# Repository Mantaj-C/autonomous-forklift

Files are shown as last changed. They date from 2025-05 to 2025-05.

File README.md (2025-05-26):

## Autonomous Forklift Robot

This project was developed as part of the Electrical Systems Design course at BCIT. It features a fully autonomous forklift robot capable of identifying packages using ArUco markers and transporting them from an unsorted truck to the appropriate sorted location.

### Features:
- **C++ software** running on a **Raspberry Pi 4**
- **OpenCV + ArUco marker detection** for package identification
- **TCP/IP communication** between control modules
- **3D printed chassis and fork**, designed in **SolidWorks**
- **Custom PCB** for motor and sensor interfacing, built with **KiCad**
- **2 stepper motors** for drivetrain movement
- **4 servo motors** for lifting and package handling
- Onboard supervisor: **Tigger** 🐯

All STL files and C++ source code are included in this repository.

---

### 🔗 Project Demo
[Video Link](https://www.linkedin.com/posts/mantaj-chauhan-951b401b5_robotics-opencv-raspberrypi-activity-7332848276444012544-EtOq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)

---

### 📂 Contents
- `/src` – All C++ source code
- `/pcb` – KiCad PCB design files
- `/cad` – STL and SolidWorks files

---

### 🤝 Contributors
- [Mantaj Chauhan](https://www.linkedin.com/in/mantaj-chauhan-951b401b5/)
- [Fuquaan Hussein](https://www.linkedin.com/in/furqaan-hussein-994ba8367/)

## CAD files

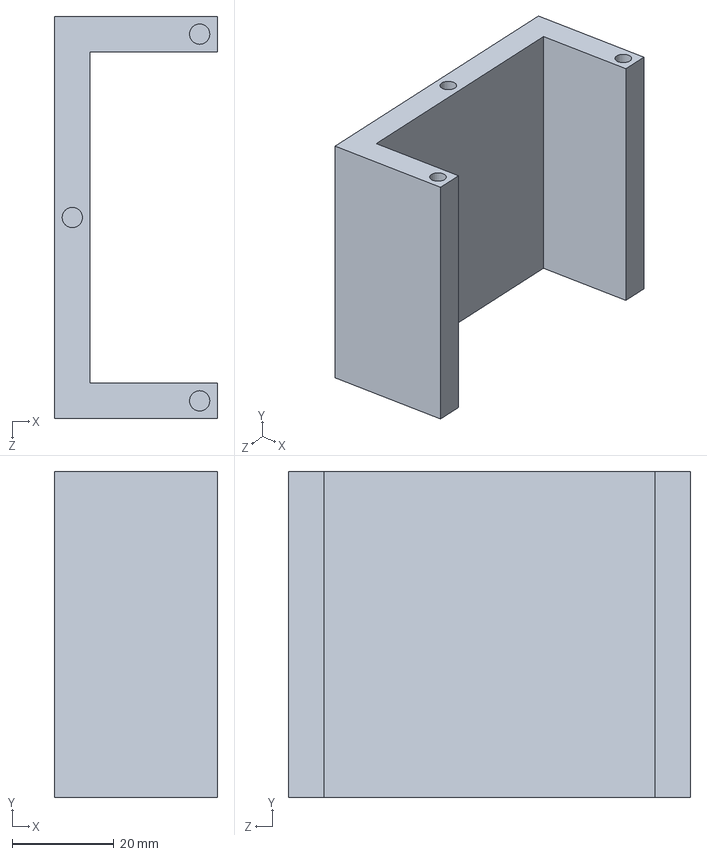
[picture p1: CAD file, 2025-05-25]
cad/sldpart/Power_Bank_Holder.SLDPRT
32.0 x 64.0 x 79.0 mm

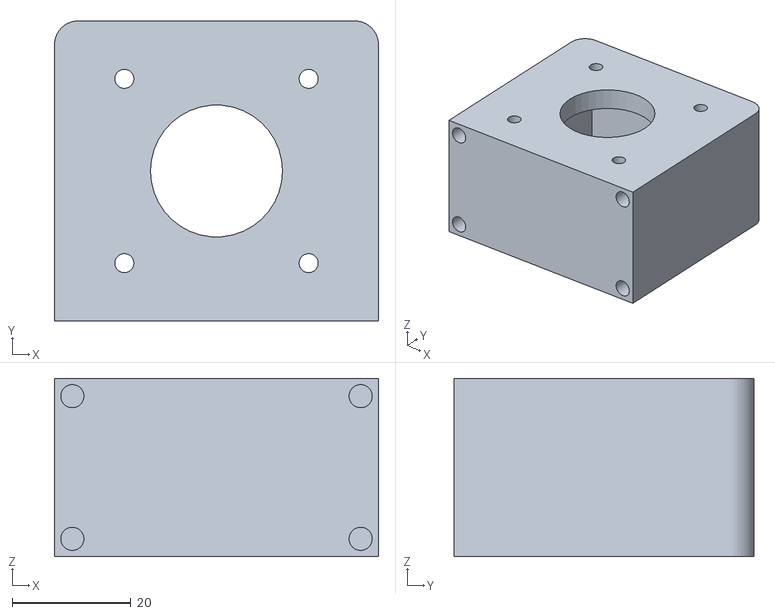
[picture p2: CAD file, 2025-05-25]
cad/stl/Stepper_Motor_Mount.STL
54.5 x 50.5 x 30.0

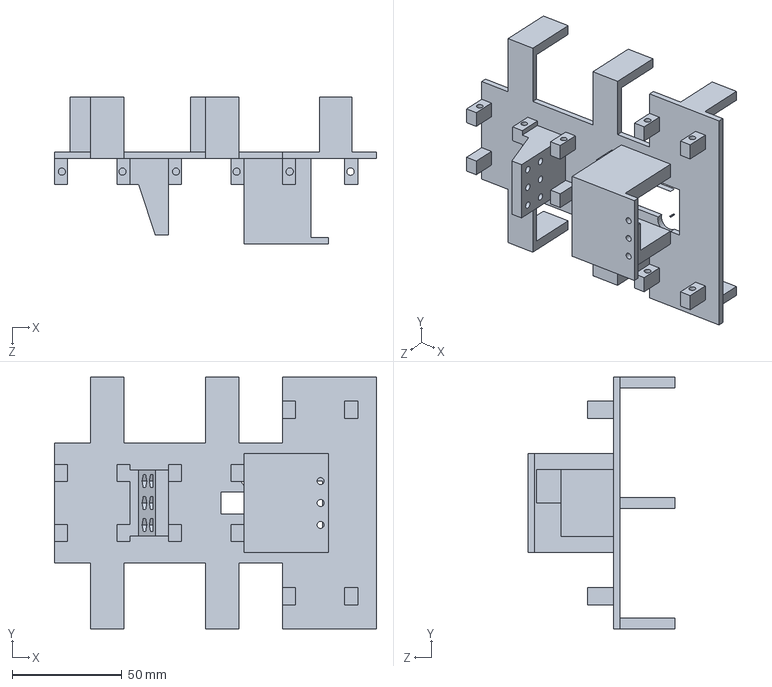
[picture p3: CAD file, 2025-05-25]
cad/sldpart/Fork_Structure.SLDPRT
147.0 x 115.0 x 67.0 mm

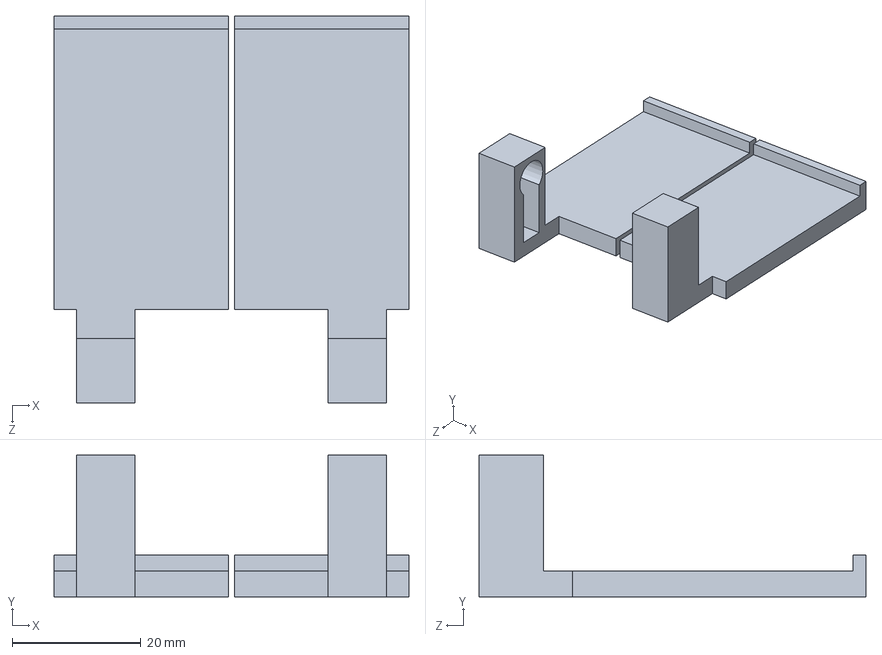
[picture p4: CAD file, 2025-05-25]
cad/sldpart/ServoFork.SLDPRT
55.0 x 22.0 x 60.0 mm

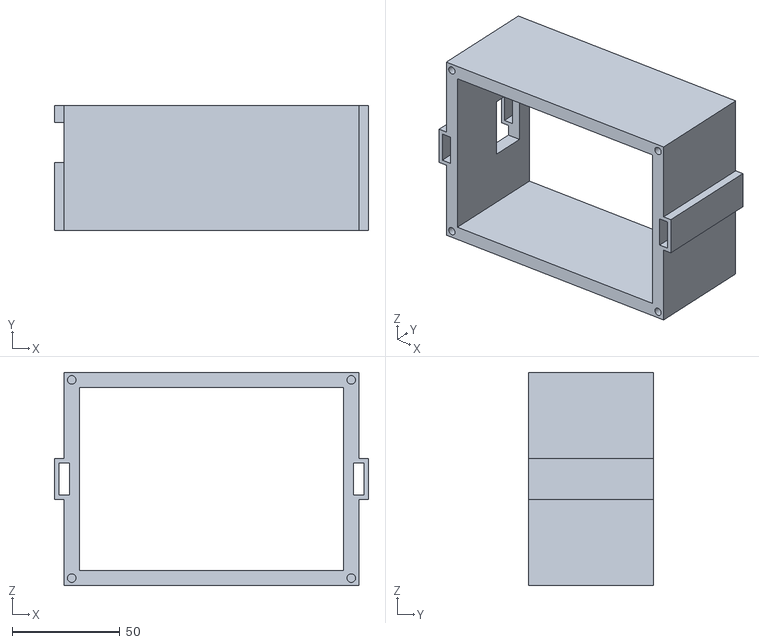
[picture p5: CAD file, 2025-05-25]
cad/stl/Drill_Battery_holder.STL
145.7 x 58.0 x 99.0

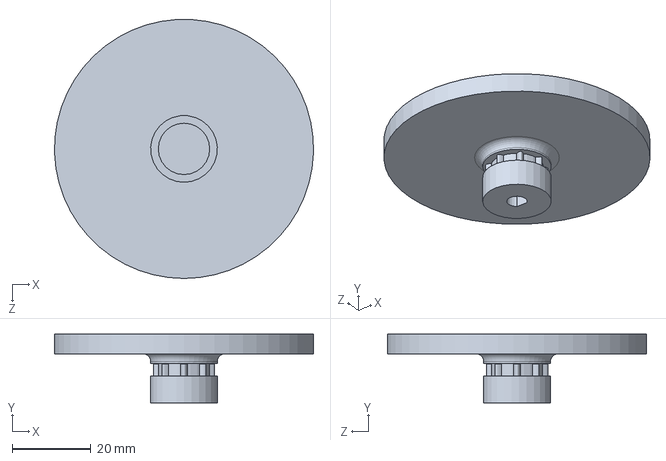
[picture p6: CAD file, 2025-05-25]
cad/sldpart/Stepper_Wheel.SLDPRT
66.0 x 17.5 x 65.9 mm

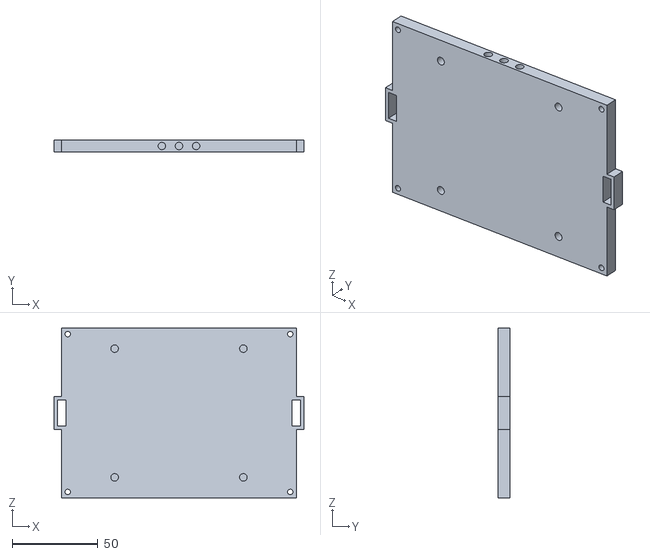
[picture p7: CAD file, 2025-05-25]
cad/stl/Drill_Cover.STL
145.7 x 7.00 x 99.0

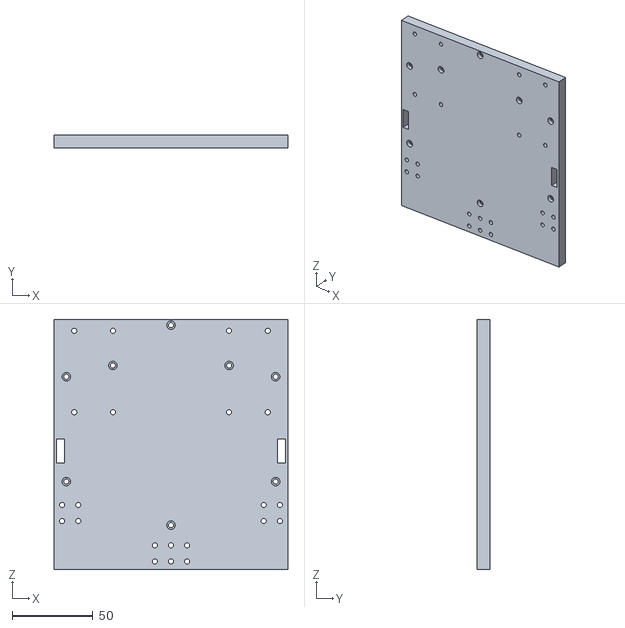
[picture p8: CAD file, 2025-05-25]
cad/stl/Base.STL
145.0 x 8.00 x 155.0

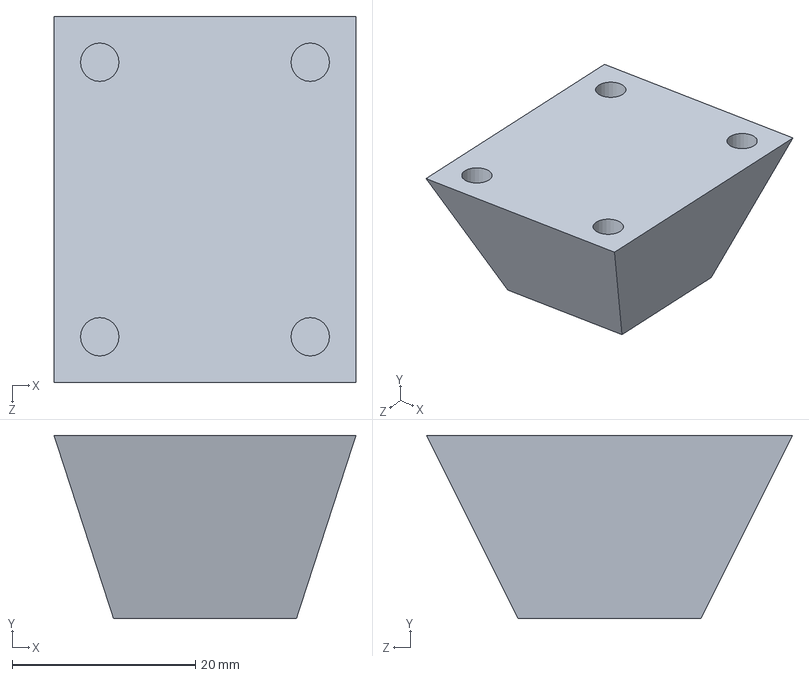
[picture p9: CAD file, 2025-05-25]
cad/sldpart/Roller_Wheel_Attachment.SLDPRT
33.0 x 20.0 x 40.0 mm

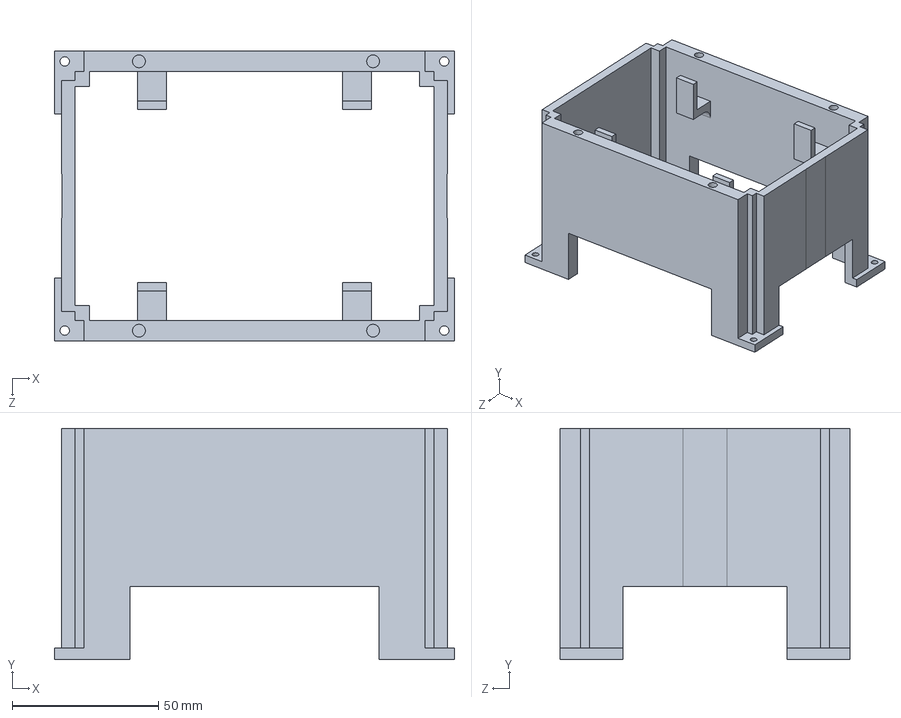
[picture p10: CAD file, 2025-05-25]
cad/sldpart/Pi_Enclosure.SLDPRT
136.7 x 79.0 x 99.0 mm

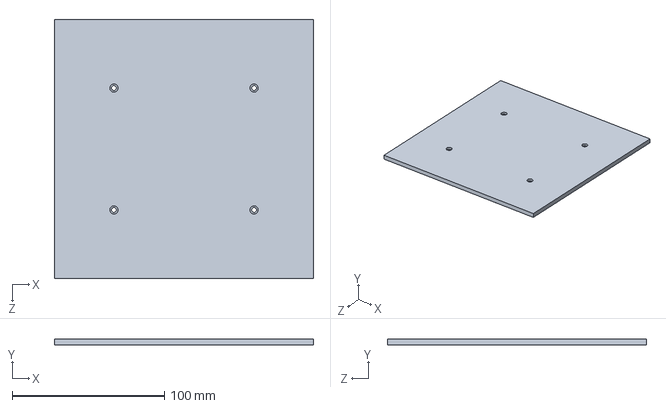
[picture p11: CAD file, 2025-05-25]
cad/sldpart/Aruco_Plate.SLDPRT
170.0 x 4.00 x 170.0 mm

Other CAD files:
cad/stl/Power_Bank_Holder.STL
cad/sldpart/Drill_Cover.SLDPRT
cad/stl/Stepper_Wheel.STL
cad/stl/Roller_Wheel_Attachment.STL
cad/stl/Pi_Enclosure.STL
cad/sldpart/Base.SLDPRT
cad/stl/Fork_Structure.STL
cad/sldpart/Drill_Battery_holder.SLDPRT
cad/sldpart/Stepper_Motor_Mount.SLDPRT
cad/stl/Aruco_Plate.STL
cad/stl/ServoFork.STL

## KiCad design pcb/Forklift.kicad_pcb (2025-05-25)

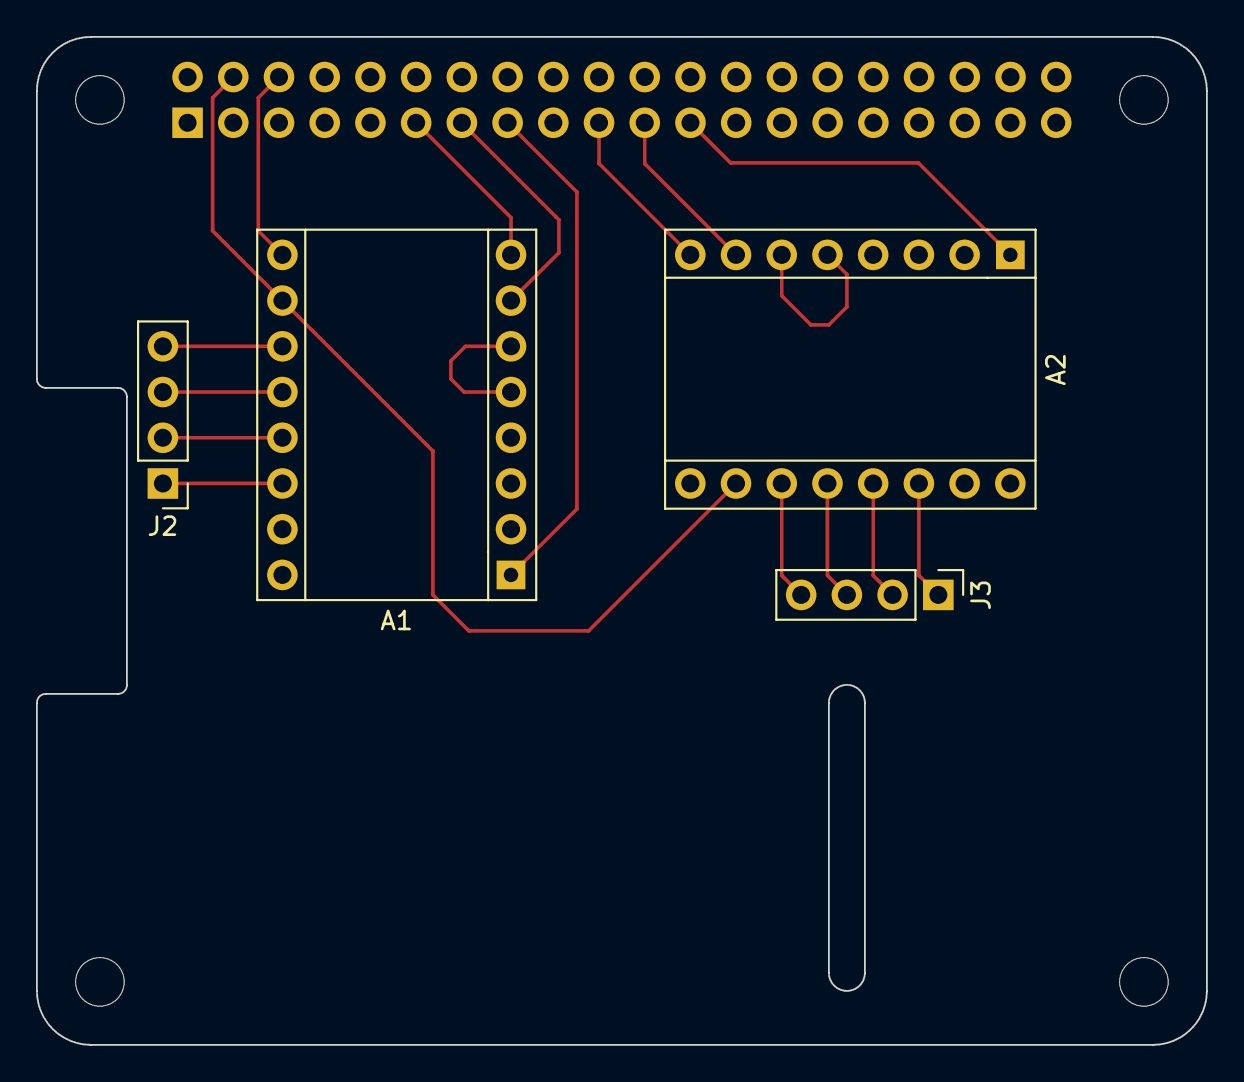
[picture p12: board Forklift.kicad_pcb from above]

Board: 2 copper layers, 65.0 x 56.0 mm, 9 parts (1 on the bottom side), 21 nets.

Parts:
A1, A2: A4988_Motor_Driver; A4988_Motor_Driver-16_15.2x20.3mm
J1: GPIO; PinSocket_2x20_P2.54mm_Vertical
J2, J3: Conn_01x04; PinHeader_1x04_P2.54mm_Vertical
MH1, MH2, MH3, MH4: MountingHole_2.7mm_M2.5

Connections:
1A_01: A1.12 (1A), J2.3
1A_02: A2.12 (1A), J3.3
1B_01: A1.11 (1B), J2.4
1B_02: A2.11 (1B), J3.4
2A_01: A1.13 (2A), J2.2
2A_02: A2.13 (2A), J3.2
2B_01: A1.14 (2B), J2.1
2B_02: A2.14 (2B), J3.1
+3V3: J1.1, J1.17
DIR_01: A1.8 (DIR), J1.11
DIR_02: A2.8 (DIR), J1.19
EN_01: A1.1 (~ENABLE), J1.15
EN_02: A2.1 (~ENABLE), J1.23
GND_01: A1.9 (GND), A2.9 (GND), J1.6, J1.9, J1.14, J1.20, J1.25, J1.30, J1.34, J1.39
MS_01: A1.2 (MS1), A1.3 (MS2), A1.4 (MS3)
MS_02: A2.2 (MS1), A2.3 (MS2), A2.4 (MS3)
unnamed: A1.5 (~RESET), A1.6 (~SLEEP)
unnamed: A2.5 (~RESET), A2.6 (~SLEEP)
STEP_01: A1.7 (STEP), J1.13
STEP_02: A2.7 (STEP), J1.21
VDD_01: A1.10 (VDD), A2.10 (VDD), J1.2, J1.4

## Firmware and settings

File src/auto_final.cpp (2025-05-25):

#include <opencv2/opencv.hpp>
#include <iostream>
#include <vector>
#include <thread>
#include <chrono>
#include <string>

#include "Client.h"
//#include "CCharuco.h"
#include "CCamera.h"
#include "CPathing.h"
#include <opencv2/aruco.hpp>


enum servos {BL = 0, BR, ML, MR};

#define WINDOW_NAME "Calibration"
#define WINDOW_SIZE cv::Size(640, 480)


#define server_ip "192.168.0.100"
#define server_port 4012

float timeout_start;

#define IMG "G 1"



void send_command(CClient &client, std::string cmd, cv::Mat &frame)
{
	std::string str;

	client.tx_str(cmd);
	std::cout << "\nClient Tx: " << cmd;


	if (cmd == IMG)
	{
		cv::Mat im;
		if (client.rx_im(im) == true)
		{
			timeout_start = cv::getTickCount();
			if (im.empty() == false)
			{
				std::cout << "\nClient Rx: Image received";
				
				#ifdef UNDISTORT
					cv::Mat cameraMatrix = (cv::Mat_<float>(3, 3) <<  1.8722871502485910e+02, 0., 2.8878842997093369e+02, 0.,  1.7784781070920499e+02, 2.4018022890173202e+02, 0., 0., 1.);
					cv::Mat distCoeffs = (cv::Mat_<float>(1, 5) <<  5.4896083310467022e-03, 2.8609542923694897e-02, -4.2421778012254633e-03, -3.8150653879379264e-02, -8.4360735642799878e-03 );
					std::cout << "\nUndistorting" << std::endl;
					cv::Mat im_undistorted;
					cv::undistort(im, im_undistorted, cameraMatrix, distCoeffs);
					std::cout << "\nUndistortion Complete" << std::endl;
					frame = im_undistorted.clone();
				#else
					frame = im.clone();
				#endif
				std::cout << "\nframe cloned" << std::endl;
				//cv::imshow("rx", im);
				std::cout << "\nImshow" << std::endl;
				cv::waitKey(10);
			}
		}
		else
		{
			if ((cv::getTickCount() - timeout_start) / cv::getTickFrequency() > 1000)
			{
				// No response, disconnect and reconnect
				std::cout << "No Response, Attempting Disconnect --> Reconnect" << std::endl;
				timeout_start = cv::getTickCount();
				client.close_socket();
				client.connect_socket(server_ip, server_port);
			}
		}
	}
	else
	{
		if (client.rx_str(str) == true)
		{
			timeout_start = cv::getTickCount();
			std::cout << "\nClient Rx: " << str;
			str.clear();
		}
		else
		{
			if ((cv::getTickCount() - timeout_start) / cv::getTickFrequency() > 1000)
			{
				// No response, disconnect and reconnect
				timeout_start = cv::getTickCount();
				client.close_socket();
				client.connect_socket(server_ip, server_port);
			}
		}
	}


}

void livestream(CClient& client, CPathing& pathing) {
	int key = 0;
	cv::Mat prevImg;
	int64 timeout_start = cv::getTickCount();
	bool flag = false;

	do {
		// 1) grab a fresh frame into currImg
		cv::Mat currImg;
		client.tx_str(IMG);
		std::cout << "\nClient Tx: " << IMG;

		if (client.rx_im(currImg)) {
			timeout_start = cv::getTickCount();

			if (!currImg.empty()) {
				// first valid frame — seed prevImg
				if (prevImg.empty()) {
					prevImg = currImg.clone();
				}

				// 2) build mask of missing (black) pixels
				cv::Mat mask;
				cv::inRange(currImg, cv::Vec3b(0,0,0), cv::Vec3b(0,0,0), mask);

				// 3) copy from prevImg wherever currImg is missing
				prevImg.copyTo(currImg, mask);

				// 4) show patched result
				std::cout << "\nClient Rx: Image received";
				cv::imshow("rx", currImg);
				//std::cout << "image columns " << currImg.cols << std::endl;

				flag = pathing.AutoRouting(currImg, cv::Point2f(610, 690), CPathing::UPPER);
				cv::imshow("auto:", currImg);

				// 5) save for next iteration
				prevImg = currImg.clone();


			}
		}
		else {

			if (!prevImg.empty()) {
				cv::imshow("rx", prevImg);
			}
			// on receive timeout, reconnect
			double elapsed = (cv::getTickCount() - timeout_start) / cv::getTickFrequency();
			if (elapsed > 1.0) {
				std::cout << "\nNo Response, reconnecting...";
				timeout_start = cv::getTickCount();
				client.close_socket();
				client.connect_socket(server_ip, server_port);
			}
		}

		

		key = cv::waitKey(10);
	} while (key != 'q' && flag == false);
}



int main(int argc, char* argv[])
{

	gpioInitialise();

	//cvui::init(WINDOW_NAME);
	// Create and display a blank image so cv::waitKey() works
	cv::Mat blankImage = cv::Mat::zeros(100, 100, CV_8UC3);
	cv::imshow("", blankImage);

	CClient client;
    
	int cmd = -1;

	timeout_start = cv::getTickCount();
	client.connect_socket(server_ip, server_port);
	CPathing pathing;

	do
	{
		std::cout << "\n (1) Image" << std::endl;
		std::cout << "\n (2) Forward" << std::endl;
		std::cout << "\n (3) Turn Right" << std::endl;
		std::cout << "\n (4) Turn Left" << std::endl;
		std::cout << "\n (5) Move backward" << std::endl;
		std::cout << "\n (6) servos up" << std::endl;
		std::cout << "\n (7) servos down" << std::endl;
    	
		do {
			cmd = cv::waitKey(1);
		} while (cmd == -1);
		std::cout << cmd << std::endl;
	
        cv::Mat im;

		switch (cmd) {

		case '1':	
			livestream(client, pathing);
			break;
		case '2':
			pathing.Move_forward(100);
			break;
		case '3':
			pathing.Turn_right(90);
			break;
		case '4':
			pathing.Turn_left(90);
			break;
		case '5':
			pathing.move_backward(100);
			break;
		case '6':
			std::this_thread::sleep_for(std::chrono::milliseconds(100));
			pathing.ServoLift(BL);
			std::this_thread::sleep_for(std::chrono::milliseconds(100));
			pathing.ServoLift(BR);
			std::this_thread::sleep_for(std::chrono::milliseconds(100));
			pathing.ServoLift(ML);
			std::this_thread::sleep_for(std::chrono::milliseconds(100));
			pathing.ServoLift(MR);
			std::this_thread::sleep_for(std::chrono::milliseconds(100));
			break;
		case '7':
			std::this_thread::sleep_for(std::chrono::milliseconds(100));
			pathing.ServoLower(BL);
			std::this_thread::sleep_for(std::chrono::milliseconds(100));
			pathing.ServoLower(BR);
			std::this_thread::sleep_for(std::chrono::milliseconds(100));
			pathing.ServoLower(ML);
			std::this_thread::sleep_for(std::chrono::milliseconds(100));
			pathing.ServoLower(MR);
			std::this_thread::sleep_for(std::chrono::milliseconds(100));
			break;
		}
	
	} while (cmd != '0');

	cv::destroyAllWindows();
	gpioTerminate();
}

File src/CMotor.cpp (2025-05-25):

#include "CMotor.h"
#include <iostream>
#include <chrono>
#include <thread>

//PWM Settings:
#define PWM_FREQ 120
// 10ms Period
#define PWM_HIGH 128 // Range 0-255, 128 is 50% duty cycle
#define PWM_LOW 0

//Left Motor Pins:
#define ENABLE_LEFT_PIN 11
#define MOTOR_LEFT_PIN 9
#define DIRECTION_LEFT_PIN 10

//#define EN_LEFT_PIN 18

//Right Motor Pins:
#define ENABLE_RIGHT_PIN 22
#define MOTOR_RIGHT_PIN 27
#define DIRECTION_RIGHT_PIN 17

//Lift Servo Stuff:

#define SERVO_PIN 18

#define SERVO_RAISE 1325
#define SERVO_LOWER 1750

#define radius_cm 3.46
#define PI_2 6.283185307179586 // 2 x Pi

#define steps_per_cm (200)/(PI_2 * radius_cm)  
#define steps_per_deg (200/360) // 200 Steps per 360 Degrees


enum  motorDirection {CCW = 0, CW };
enum  motorState {ENABLED = 0, DISABLED };

CMotor::CMotor() {

    //Initialise GPIO:

    _PWM_FREQ = PWM_FREQ;

    //Set the gpio pins:
    gpioSetMode(ENABLE_LEFT_PIN, PI_OUTPUT);
    gpioSetMode(ENABLE_RIGHT_PIN, PI_OUTPUT);

    gpioSetMode(DIRECTION_LEFT_PIN, PI_OUTPUT);
    gpioSetMode(DIRECTION_RIGHT_PIN, PI_OUTPUT);

    gpioSetMode(MOTOR_LEFT_PIN, PI_OUTPUT);
    gpioSetMode(MOTOR_RIGHT_PIN, PI_OUTPUT);

    gpioSetMode(SERVO_PIN, PI_OUTPUT);

    //Diable Motors:
    gpioWrite(ENABLE_LEFT_PIN, ENABLED);
    gpioWrite(ENABLE_RIGHT_PIN, ENABLED);
    
    //Set PWM Frequency:
    gpioSetPWMfrequency(MOTOR_LEFT_PIN, PWM_FREQ); 
    gpioSetPWMfrequency(MOTOR_RIGHT_PIN, PWM_FREQ);

    gpioPWM(MOTOR_LEFT_PIN, PWM_LOW);
    gpioPWM(MOTOR_RIGHT_PIN, PWM_LOW);

}

CMotor::~CMotor() {
    //Shut off Motors:
    stop();
    std::cout << "Stopping Motors..." << std::endl;
}


void CMotor::servoLift(int height,int pin) {
    //Set Servo to 180 degrees:
    gpioServo(pin, height);
}

void CMotor::servoLower(int height,int pin) {
    //Set Servo to 0 degrees:
    gpioServo(pin, height);
}   

void CMotor::forward() {

    //Set Motor Direction:
    gpioWrite(DIRECTION_LEFT_PIN, CW);
    gpioWrite(DIRECTION_RIGHT_PIN, CCW);
}

void CMotor::reverse() {

    //Set Motor Direction:
    gpioWrite(DIRECTION_LEFT_PIN, CCW);
    gpioWrite(DIRECTION_RIGHT_PIN, CW);
}

void CMotor::left() {

    //Set Motor Direction:
    gpioWrite(DIRECTION_LEFT_PIN, CCW);
    gpioWrite(DIRECTION_RIGHT_PIN, CCW);
}

void CMotor::right() {

    //Set Motor Direction:
    gpioWrite(DIRECTION_LEFT_PIN, CW);
    gpioWrite(DIRECTION_RIGHT_PIN, CW);
}

void CMotor::start() {

    //Enable Motors:
    //gpioWrite(ENABLE_LEFT_PIN, ENABLED);
    //gpioWrite(ENABLE_RIGHT_PIN, ENABLED);

    gpioPWM(MOTOR_LEFT_PIN, PWM_HIGH);
    gpioPWM(MOTOR_RIGHT_PIN, PWM_HIGH);
}

void CMotor::stop() {

    //Disable Motors:
    //gpioWrite(ENABLE_LEFT_PIN, DISABLED);
    //gpioWrite(ENABLE_RIGHT_PIN, DISABLED);

    gpioPWM(MOTOR_LEFT_PIN, PWM_LOW);
    gpioPWM(MOTOR_RIGHT_PIN, PWM_LOW);
}

void CMotor::setPWM(int PWM) {

    _PWM_FREQ = PWM;
    gpioSetPWMfrequency(MOTOR_LEFT_PIN, _PWM_FREQ);
    gpioSetPWMfrequency(MOTOR_RIGHT_PIN, _PWM_FREQ);

}

int CMotor::getFrequency() {return _PWM_FREQ; }

void CMotor::TravelTiming(float distance_cm) {
    int time_ms = distance_cm * steps_per_cm * (1000/_PWM_FREQ); // Distance x Steps/Distance x Time/Step
    std::this_thread::sleep_for(std::chrono::milliseconds(time_ms));
    //std::cout << "Time Delay: " << time_ms << std::endl;
}

void CMotor::TurnTiming(float angle_deg) {
    int time_ms = angle_deg * steps_per_deg* (1000/_PWM_FREQ); // Angle x Steps/Angle x Time/Step
    std::this_thread::sleep_for(std::chrono::milliseconds(time_ms));
}

void CMotor::MotorTest() {

    std::cout << "Motor Test:" << std::endl;
    bool exit = false;

    do {

        std::cout << "Press 'w' to forward" << std::endl;
        std::cout << "Press 's' to reverse" << std::endl;
        std::cout << "Press 'a' to left" << std::endl;
        std::cout << "Press 'd' to right" << std::endl;
        std::cout << "Press 'e' to start" << std::endl;
        std::cout << "Press 'r' to stop" << std::endl;
        std::cout << "Press '+' to increase PWM Frequency" << std::endl;
        std::cout << "Press '-' to decrease PWM Frequency" << std::endl;
        std::cout << "Press 'q' to quit" << std::endl;
        std::string input;
        std::cin >> input;

        if (input == "w") {
            forward();
            setPWM(0);
            start();
            RampUp(0, 200, 10);
            TravelTiming(30.48); // Forward 1cm
            stop();
        } else if (input == "s") {
            reverse();
            start();
            TravelTiming(1); // Reverse 1cm
            stop();
        } else if (input == "a") {
            left();
            start();
            TurnTiming(4); // Turn 1deg left
            stop();
        } else if (input == "d") {
            right();
            start();
            TurnTiming(45); // Turn 1deg right
            stop();
        } else if (input == "e") {
            start();
        } else if (input == "r") {
            stop();
        } else if (input == "+") {
            setPWM(_PWM_FREQ + 10);
            std::cout << "PWM Frequency: " << getFrequency() << std::endl;
        } else if (input == "-") {  
            setPWM(_PWM_FREQ - 10);
            std::cout << "PWM Frequency: " << getFrequency() << std::endl;
        } else if (input == "q") {
            exit = true;
            std::cout << "Exiting..." << std::endl;
        }

    } while (exit == false);
    
}


void CMotor::RampUp(int startPWM, int endPWM, int duration_ms) {
    int time_ms = duration_ms;
    for (int i = startPWM; i <= endPWM; i++) {
        setPWM(i);
        std::this_thread::sleep_for(std::chrono::milliseconds(time_ms));
    }
}

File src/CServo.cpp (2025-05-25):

#include "CServo.h"


#define ML_LO 1730
#define MR_LO 1525
#define BL_LO 2065
#define BR_LO 2110

#define ML_HI 1600
#define MR_HI 1600
#define BL_HI 1880
#define BR_HI 2205

CServo::CServo(int gpio_pin, bool Mirror, int upper, int lower) {
   
    servo_upper = upper;
    servo_lower = lower;
  
    pin = gpio_pin;
    Mirrored = Mirror;
}

CServo::~CServo() {

}

void CServo::adjust_upper(int move) {
    if (Mirrored) {
        servo_upper -= move;
    }
    else {
        servo_upper += move;
    }
}

void CServo::adjust_lower(int move) {
    if (Mirrored) {
        servo_lower -= move;
    }
    else {
        servo_lower += move;
    }
}

int CServo::get_upper() {
    return servo_upper;
}

int CServo::get_lower() {
    return servo_lower;
}

int CServo::get_pin() {
    return pin;
}
